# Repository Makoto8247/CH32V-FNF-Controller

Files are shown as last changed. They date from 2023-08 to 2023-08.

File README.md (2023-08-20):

# CH32V-FNF-Controller
## 概要
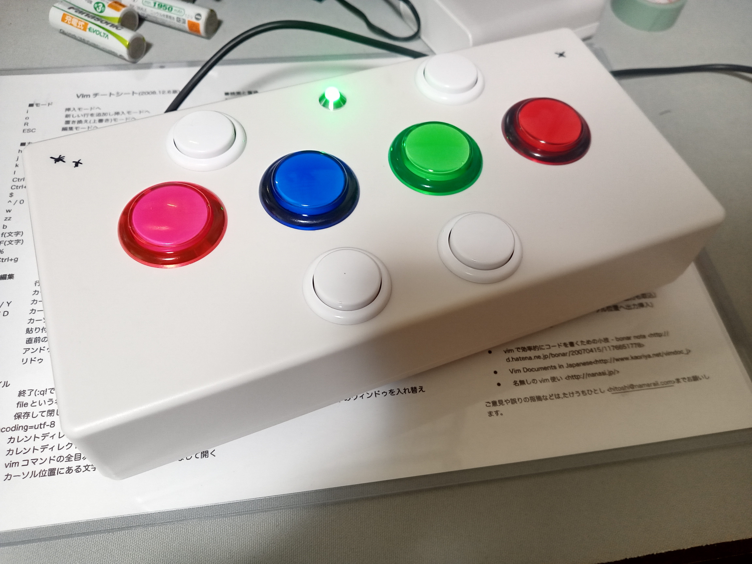
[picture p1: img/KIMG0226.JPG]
Controller

CH32V003F4P6を使用しFridayNightFunkinの専用コントローラーを作成しました。
## パーツ
- CH32V003F4P6 * 1
- CH9329 * 1
- ボタン * 8 or 9
- LED * 1
- XHコネクタ * 9
- USB Type-Cコネクタ * 1
- リセッタブルヒューズ 500mA * 1
- コンデンサ 0.1μF * 3
- 抵抗
  - 5k1 * 1
  - 10k * 7
  - 200 * 1
## マイコン
CH32V003F4P6用に設計しており、MounRiverを使用しています。  
他のマイコンを使用する場合、mainファイルの書き換えやPCBデータの書き換えが必要になる場合があります。
## PCB
ソフトウェアはKiCadを使用しています。  
outputフォルダに既にガーバーデータを出力したファイルを格納しているのでそこから基盤を作成しても構いません。しかし、初めて基盤を作成したので不具合がある可能性があります。  
スペース用のボタンは2つ使えるようにしていますが、1つのみでも使えるようにしています。

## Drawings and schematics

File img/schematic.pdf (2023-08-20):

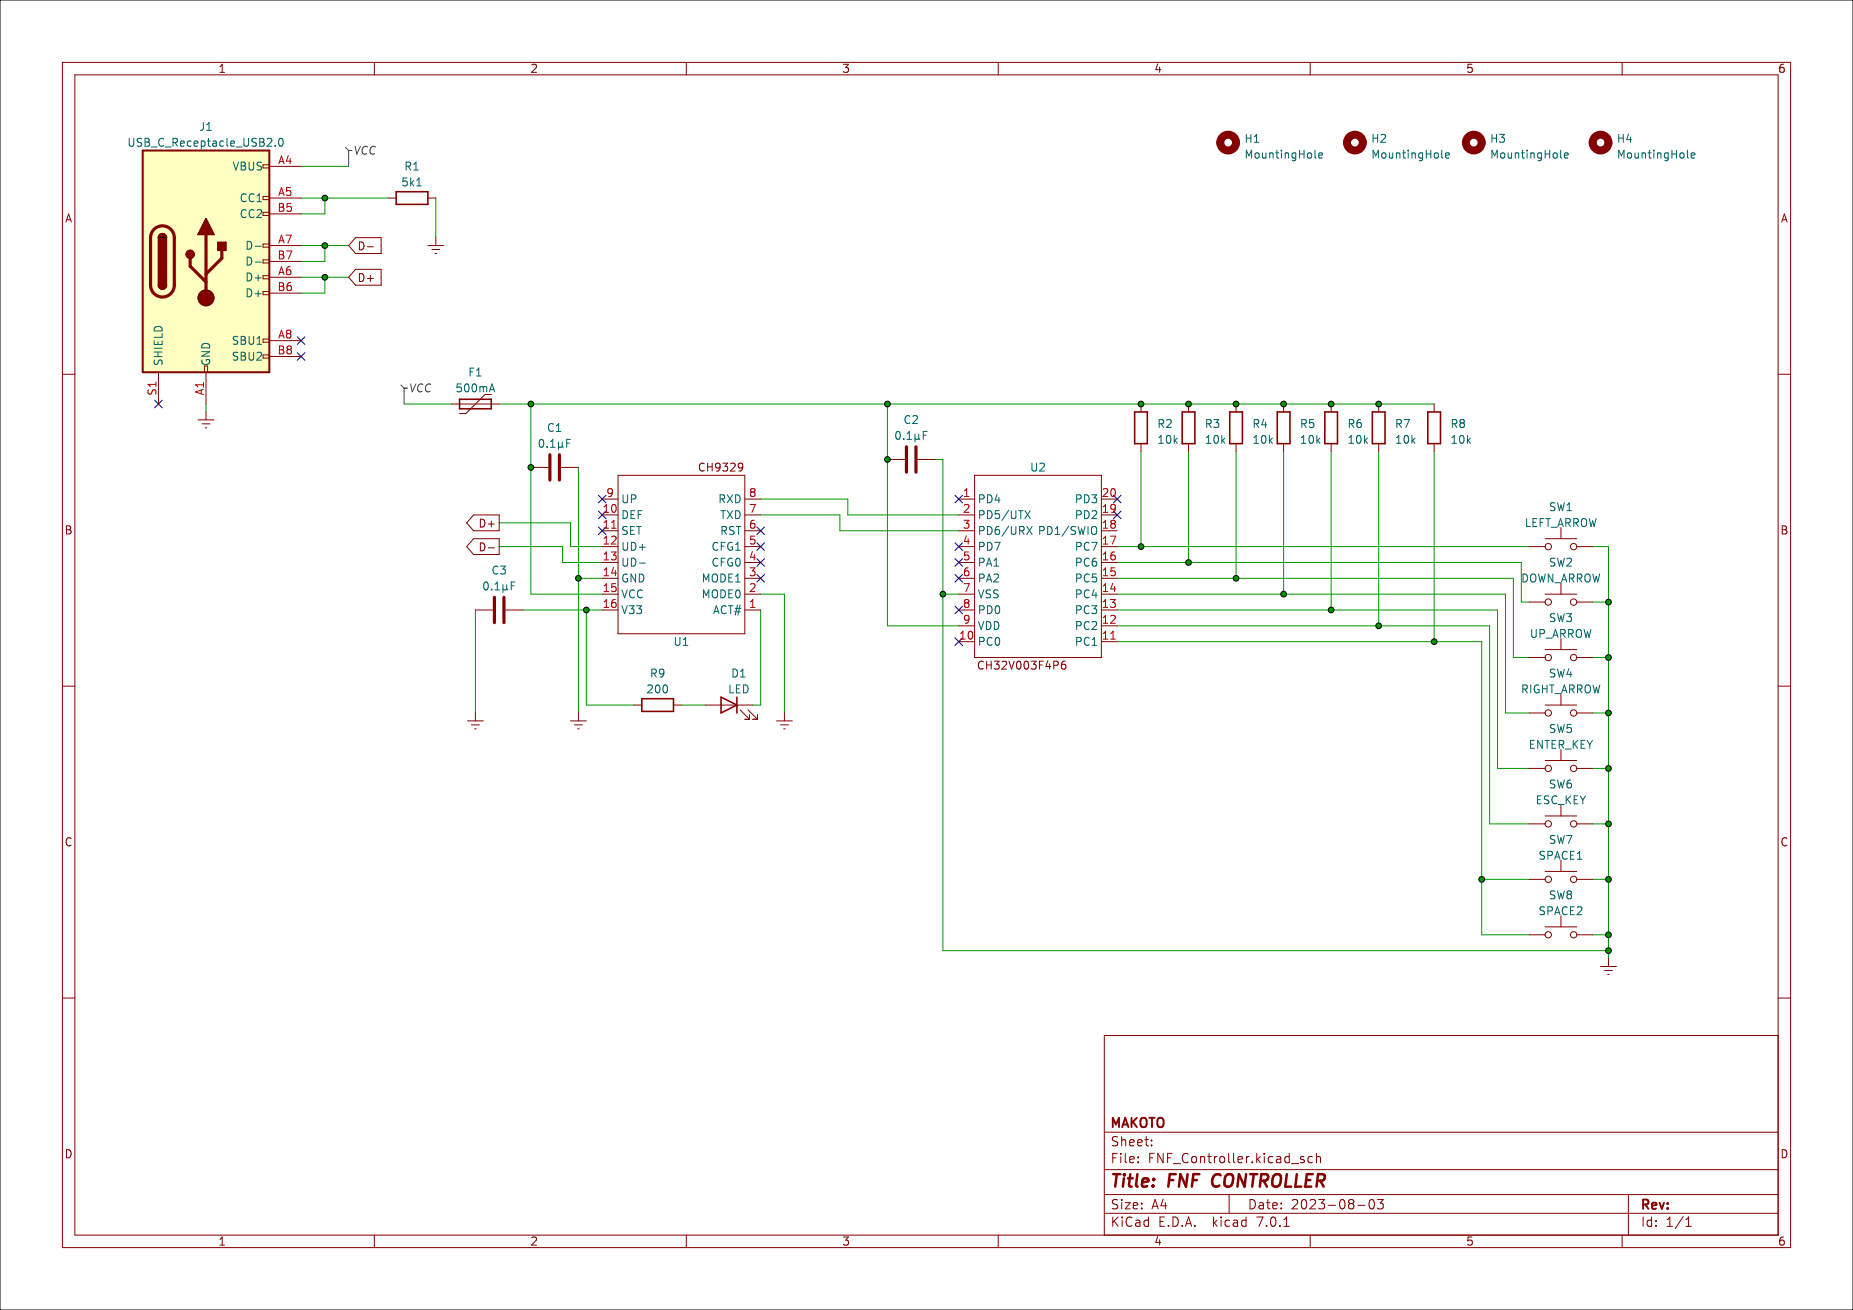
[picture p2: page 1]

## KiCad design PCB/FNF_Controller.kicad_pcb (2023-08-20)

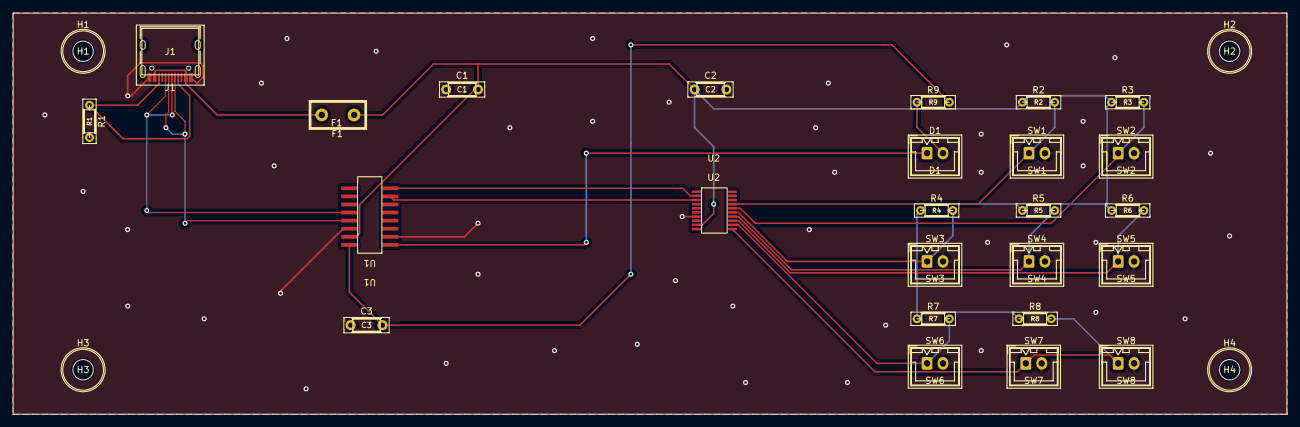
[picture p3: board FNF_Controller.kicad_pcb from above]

Board: 2 copper layers, 200.0 x 63.0 mm, 29 parts (0 on the bottom side), 18 nets.

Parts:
C1, C2, C3: 0.1μF; C_Disc_D4.3mm_W1.9mm_P5.00mm
D1: LED; JST_XH_B2B-XH-A_1x02_P2.50mm_Vertical
F1: 500mA; Fuse_Littelfuse_395Series
H1, H2, H3, H4: MountingHole; MountingHole_3.2mm_M3
J1: USB_C_Receptacle_USB2.0; USB_C_Receptacle_HRO_TYPE-C-31-M-12
R1: 5k1; R_Axial_DIN0204_L3.6mm_D1.6mm_P5.08mm_Horizontal
R2, R3, R4, R5, R6, R7, R8: 10k; R_Axial_DIN0204_L3.6mm_D1.6mm_P5.08mm_Horizontal
R9: 3k3; R_Axial_DIN0204_L3.6mm_D1.6mm_P5.08mm_Horizontal
SW1: LEFT_ARROW; JST_XH_B2B-XH-A_1x02_P2.50mm_Vertical
SW2: DOWN_ARROW; JST_XH_B2B-XH-A_1x02_P2.50mm_Vertical
SW3: UP_ARROW; JST_XH_B2B-XH-A_1x02_P2.50mm_Vertical
SW4: RIGHT_ARROW; JST_XH_B2B-XH-A_1x02_P2.50mm_Vertical
SW5: ENTER_KEY; JST_XH_B2B-XH-A_1x02_P2.50mm_Vertical
SW6: ESC_KEY; JST_XH_B2B-XH-A_1x02_P2.50mm_Vertical
SW7: SPACE1; JST_XH_B2B-XH-A_1x02_P2.50mm_Vertical
SW8: SPACE2; JST_XH_B2B-XH-A_1x02_P2.50mm_Vertical
U1: ch9329
U2: ch32v003f4p6

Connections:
D+: J1.A6 (D+), J1.B6 (D+), U1.12 (UD+)
D-: J1.A7 (D-), J1.B7 (D-), U1.13 (UD-)
GNDREF: C1.1, C2.2, C3.1, J1.A1 (GND), J1.A12 (GND), J1.B1 (GND), J1.B12 (GND), R1.2, SW1.2 (A), SW2.2 (A), SW3.2 (A), SW4.2 (A), SW5.2 (A), SW6.2 (A), SW7.2 (A), SW8.2 (A), U1.2 (MODE0), U1.14 (GND), U2.7 (VSS)
unnamed: D1.2 (A), R9.1
unnamed: D1.1 (K), U1.1 (ACT#)
unnamed: J1.A5 (CC1), J1.B5 (CC2), R1.1
unnamed: F1.2, J1.A4 (VBUS), J1.A9 (VBUS), J1.B4 (VBUS), J1.B9 (VBUS)
unnamed: U1.8 (RXD), U2.2 (PD5/UTX)
unnamed: U1.7 (TXD), U2.3 (PD6/URX)
unnamed: C3.2, R9.2, U1.16 (V33)
unnamed: C1.2, C2.1, F1.1, R2.1, R3.1, R4.1, R5.1, R6.1, R7.1, R8.1, U1.15 (VCC), U2.9 (VDD)
unnamed: R8.2, SW7.1 (A), SW8.1 (A), U2.11 (PC1)
unnamed: R7.2, SW6.1 (A), U2.12 (PC2)
unnamed: R6.2, SW5.1 (A), U2.13 (PC3)
unnamed: R5.2, SW4.1 (A), U2.14 (PC4)
unnamed: R4.2, SW3.1 (A), U2.15 (PC5)
unnamed: R3.2, SW2.1 (A), U2.16 (PC6)
unnamed: R2.2, SW1.1 (A), U2.17 (PC7)

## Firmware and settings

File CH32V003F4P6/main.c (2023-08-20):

/********************************** (C) COPYRIGHT *******************************
 * File Name          : main.c
 * Author             : WCH
 * Version            : V1.0.0
 * Date               : 2022/08/08
 * Description        : Main program body.
 *********************************************************************************
 * Copyright (c) 2021 Nanjing Qinheng Microelectronics Co., Ltd.
 * Attention: This software (modified or not) and binary are used for 
 * microcontroller manufactured by Nanjing Qinheng Microelectronics.
 *******************************************************************************/

/*
 *@Note
 *Multiprocessor communication mode routine:
 *Master:USART1_Tx(PD5)\USART1_Rx(PD6).
 *This routine demonstrates that USART1 receives the data sent by CH341 and inverts
 *it and sends it (baud rate 115200).
 *
 *Hardware connection:PD5 -- Rx
 *                     PD6 -- Tx
 *
 */

#include "debug.h"


/* Global define */
#define LEFT_ARROW_PIN  GPIO_Pin_7
#define DOWN_ARROW_PIN  GPIO_Pin_6
#define UP_ARROR_PIN    GPIO_Pin_5
#define RIGHT_ARROR_PIN GPIO_Pin_4
#define ENTER_KEY_PIN   GPIO_Pin_3
#define ESC_KEY_PIN     GPIO_Pin_2
#define SPACE_KEY_PIN   GPIO_Pin_1

/* Global Variable */

uint16_t send_data[14] = {
        0x57, 0xAB, // HEAD
        0x00,       // ADDR
        0x02,       // CMD
        0x08,       // LEN
        0x00,       // SPECIAL KEY
        0x00,       // SPACE
        0x00,       // LEFT KEY
        0x00,       // DOWN KEY
        0x00,       // UP KEY
        0x00,       // RIGHT KEY
        0x00,       // ENTER KEY
        0x00,       // ESC KEY or SPACE KEY
        0x00        // CHECK SUM
};
uint16_t old_send_data[14] = {
        0x57, 0xAB, // HEAD
        0x00,       // ADDR
        0x02,       // CMD
        0x08,       // LEN
        0x00,       // SPECIAL KEY
        0x00,       // SPACE
        0x00,       // LEFT KEY
        0x00,       // DOWN KEY
        0x00,       // UP KEY
        0x00,       // RIGHT KEY
        0x00,       // ENTER KEY
        0x00,       // ESC KEY or SPACE KEY
        0x00        // CHECK SUM
};


void USARTx_CFG(void)
{
    GPIO_InitTypeDef  GPIO_InitStructure = {0};
    USART_InitTypeDef USART_InitStructure = {0};

    RCC_APB2PeriphClockCmd(RCC_APB2Periph_GPIOD | RCC_APB2Periph_USART1, ENABLE);

    /* USART1 TX-->D.5   RX-->D.6 */
    GPIO_InitStructure.GPIO_Pin = GPIO_Pin_5;
    GPIO_InitStructure.GPIO_Speed = GPIO_Speed_50MHz;
    GPIO_InitStructure.GPIO_Mode = GPIO_Mode_AF_PP;
    GPIO_Init(GPIOD, &GPIO_InitStructure);
    GPIO_InitStructure.GPIO_Pin = GPIO_Pin_6;
    GPIO_InitStructure.GPIO_Mode = GPIO_Mode_IN_FLOATING;
    GPIO_Init(GPIOD, &GPIO_InitStructure);

    USART_InitStructure.USART_BaudRate = 9600;
    USART_InitStructure.USART_WordLength = USART_WordLength_8b;
    USART_InitStructure.USART_StopBits = USART_StopBits_1;
    USART_InitStructure.USART_Parity = USART_Parity_No;
    USART_InitStructure.USART_HardwareFlowControl = USART_HardwareFlowControl_None;
    USART_InitStructure.USART_Mode = USART_Mode_Tx | USART_Mode_Rx;

    USART_Init(USART1, &USART_InitStructure);
    USART_Cmd(USART1, ENABLE);
}

void BUTTON_CFG(void)
{
    GPIO_InitTypeDef GPIO_InitStructure = {0};
    RCC_APB2PeriphClockCmd(RCC_APB2Periph_GPIOC, ENABLE);
    GPIO_InitStructure.GPIO_Pin = GPIO_Pin_All;
    GPIO_InitStructure.GPIO_Speed = GPIO_Speed_50MHz;
    GPIO_InitStructure.GPIO_Mode = GPIO_Mode_IN_FLOATING;
    GPIO_Init(GPIOC, &GPIO_InitStructure);
}

uint16_t CHECK_SUM(void)
{
    uint sum = 0;
    for (int i=0;i<13;i++) sum += (uint)send_data[i];
    return (uint16_t)sum;
}

void WRITE_DATA(void)
{
    send_data[13] = CHECK_SUM();
    for(int i=0;i<14;i++){
        USART_SendData(USART1, send_data[i]);
        while(USART_GetFlagStatus(USART1, USART_FLAG_TXE) == RESET);
    }
    while(USART_GetFlagStatus(USART1, USART_FLAG_TC) == RESET);

}

uint8_t DATA_EQUAL(void)
{
    for(int i=7;i<13;i++){
       if(old_send_data[i] != send_data[i]) return 1;
    }
    return 0;
}

void DATA_CPY(void)
{
    for(int i=7;i<13;i++) old_send_data[i] = send_data[i];
}

int main(void)
{
    NVIC_PriorityGroupConfig(NVIC_PriorityGroup_2);
    SystemCoreClockUpdate();
    Delay_Init();
    USARTx_CFG();
    BUTTON_CFG();
    DATA_CPY();

    while(1)
    {
        /* input key scan */
        send_data[7]  = (1-GPIO_ReadInputDataBit(GPIOC, LEFT_ARROW_PIN))  * 0x50;
        send_data[8]  = (1-GPIO_ReadInputDataBit(GPIOC, DOWN_ARROW_PIN))  * 0x51;
        send_data[9]  = (1-GPIO_ReadInputDataBit(GPIOC, UP_ARROR_PIN))    * 0x52;
        send_data[10] = (1-GPIO_ReadInputDataBit(GPIOC, RIGHT_ARROR_PIN)) * 0x4F;
        send_data[11] = (1-GPIO_ReadInputDataBit(GPIOC, ENTER_KEY_PIN))   * 0x28;
        send_data[12] = (1-GPIO_ReadInputDataBit(GPIOC, ESC_KEY_PIN))     * 0x58;
        if (send_data[12] != 0x58) send_data[12] = (1-GPIO_ReadInputDataBit(GPIOC, SPACE_KEY_PIN))   * 0x2C;

        if (DATA_EQUAL() == 1) WRITE_DATA();

        DATA_CPY();
    }
}
